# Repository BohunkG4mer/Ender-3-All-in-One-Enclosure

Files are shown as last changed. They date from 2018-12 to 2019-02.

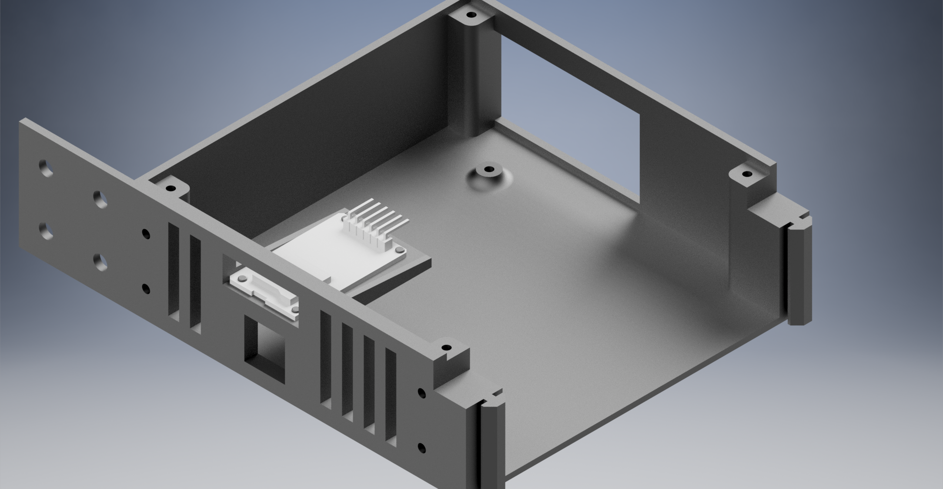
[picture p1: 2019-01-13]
Photos/card reader 2.png

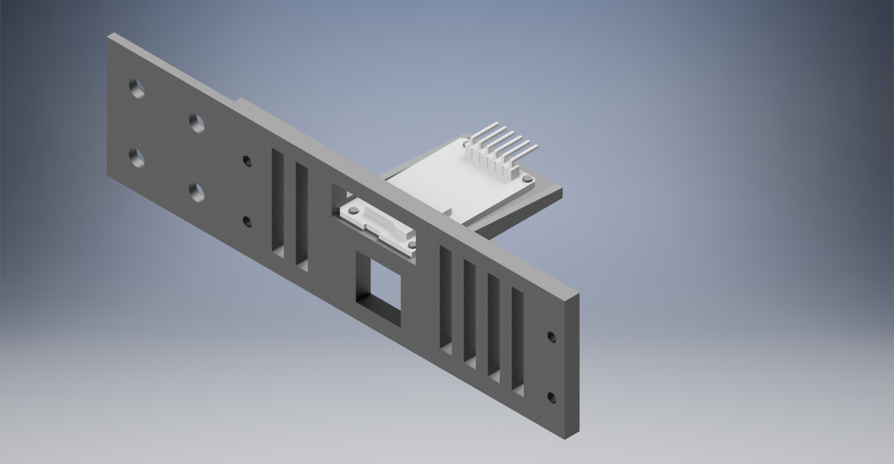
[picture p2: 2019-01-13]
Photos/card reader.png

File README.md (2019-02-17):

# Ender 3 All in One Modular Electronics Enclosure

This project is about making an all-in-one solution for upgrading your Ender 3 electronics. I started with the good old Ender 3, but quickly realized I wanted to expand the Ender 3's capabilities, and upgrade the original mainboard. I looked on Thingiverse, but couldn't really find a solution I liked. Thus began the journey of creating my own, all in one solution. I'm not new to CAD, but this is my first major project and my first Github thing, so bear with me and I'm totally open to suggestions and improvements.

Initially I started with these goals in mind:

- Be able to fit many types of mainboards, including the MKS Gen 1.4 and MKS Gen L.
- Be able to fit a Raspberry Pi internally for permanent installment, for use with Klipper firmware.
- Have a modular design to allow customization for the user's desires.
- Of course, have it all printable on a stock Ender 3.
- Be open source, and allow users to not only download and print as is, but create their own versions using my source files.
- Minimize material usage and print time when possible

Many improvements have been made and will continue to be made since the original upload on Thingiverse.  Because the Github was created later than the original project, V1.0 on Github is the newest version of the files uploaded to Thingiverse, and the next version on Github will likely be V2.0.

This Github project will let you follow the progress of my design journey, submit issues and design improvement suggestions, request additional modules and/or versions of parts, request added component compatibility, among other things. It is also the place to download all STLs and Source files, as I don't want to have to manage two separate pages and websites with the same files.

https://imgur.com/a/7V5CoWO

If you'd like to contribute to the development, feel free to donate.  It's very much appreciated!

http://paypal.me/BladeScraper

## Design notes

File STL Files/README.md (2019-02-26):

These are the STL files.

Parts and their discription:

## Base Left No Front Panel:
This is the left half of the main base. It doesn't have a front panel which makes printing much faster than previous versions of the enclosure.  The front panel is a separate part.

## Base Right No Front Panel:
This is the right half of the main base. It doesn't have a front panel which makes printing much faster than previous versions of the enclosure.  The front panel is a separate part.

## Base Left Front Panel:
This screws onto the base left part using M3x8 screws.  

## Base Right Front Panel:
This screws onto the base right part using M3x8 screws.  

## Base Cover Left:
This screws into the top of the base to cover it using M3x8 screws.

## Base Cover Right:
This screws into the top of the base to cover it using M3x8 screws.

## RPi3 Mount:
This is the Raspberry Pi3 mount module.  Screws onto the right base with M3x6 screws.  The Pi screws to it using M2.5x6 screws.

## Regulator Mount: 
This is for mounting LM2596 regulators and the MOSFET modules from Amazon.  Screws to the base using M3x6 screws.

## Base Left Front Panel Card Reader
For use with an Arduino SD Card reader.  Untested.
https://smile.amazon.com/WINGONEER-reader-module-interface-conversion/dp/B06XHJJWNC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

## Base Cover Left 80mm Fan
For use with a 80x10 or 80x25 fan.  Fan will mount on top of the cover as there's probably not sufficient room under it.  A 80x10 fan might work under the cover, but a 80x25 will definitely not.

## Base Cover Left 60mm Fan
This screws into the top of the base to cover it using M3x8 screws.

## Base Cover Right 80mm Fan
Added 80mm Fan Version of Base Cover Right.

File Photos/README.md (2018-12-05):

This folder contains photos of my personal Ender 3 with the electronics enclosure installed.  Mainly to be used as an example to look at when upgrading your own Ender 3.

The photos may not contain the latest designes immediately after release, but they should still give you a good reference to look at.

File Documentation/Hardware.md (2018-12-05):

This is a list of required hardware for assembly.

For Attaching the Front Panels to the Base parts:
- 8 x M3x8 Screws

For attaching RPi3 to RPi3 Mount: 
- 4 x M2.5x6 screws

For attaching RPi3 Mount to Base:
- 4 x M3x6 screws

For attaching MKS mainboard to Base:
- 4 x M3x6 screws

For attaching Base Cover left and Base Cover right:
- 4 x M3x8 per side

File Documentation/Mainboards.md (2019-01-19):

This is a list of current compatible mainboards for the enclosure.  

1. MKS Gen 1.4
2. MKS Gen L
3. MKS Rumba V1.0 (untested)

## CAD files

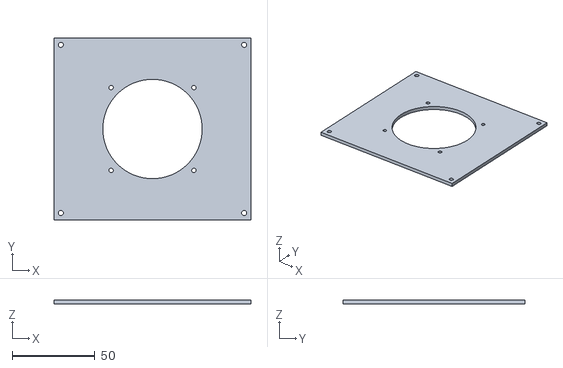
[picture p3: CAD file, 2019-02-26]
STL Files/Base Cover Left 60mm Fan.stl
119.0 x 110.2 x 2.50

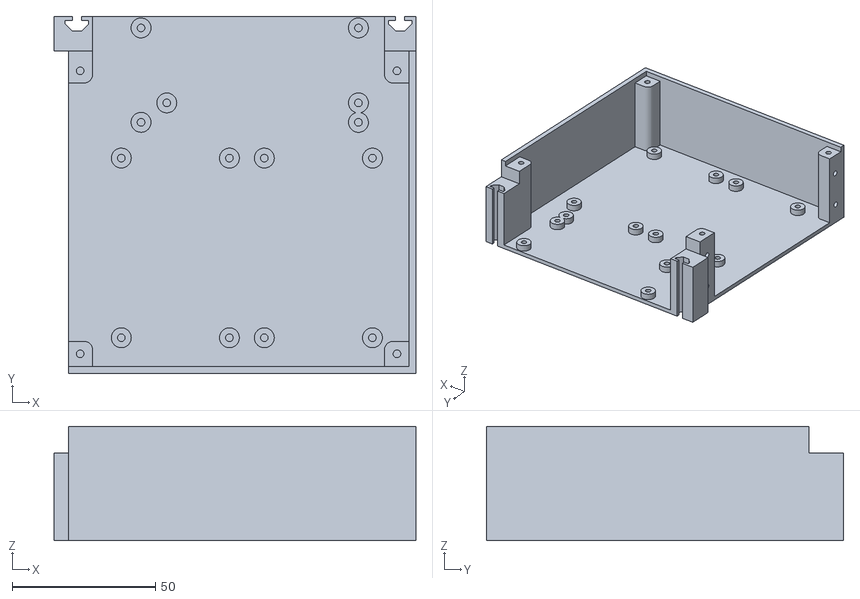
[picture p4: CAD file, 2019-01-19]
STL Files/Base Right No Front Panel.stl
126.5 x 124.8 x 40.0

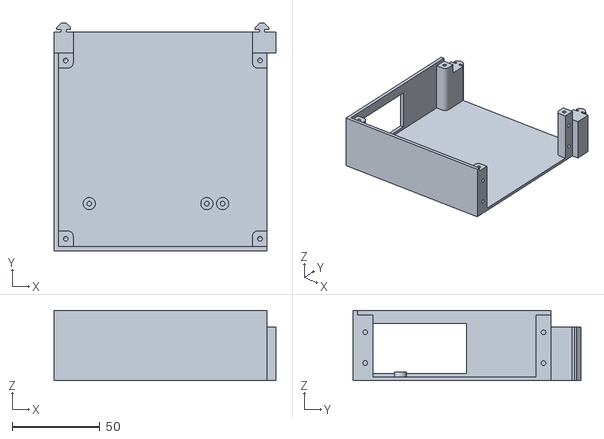
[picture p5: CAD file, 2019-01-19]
STL Files/Base Left No Front Panel.stl
126.5 x 129.7 x 40.0

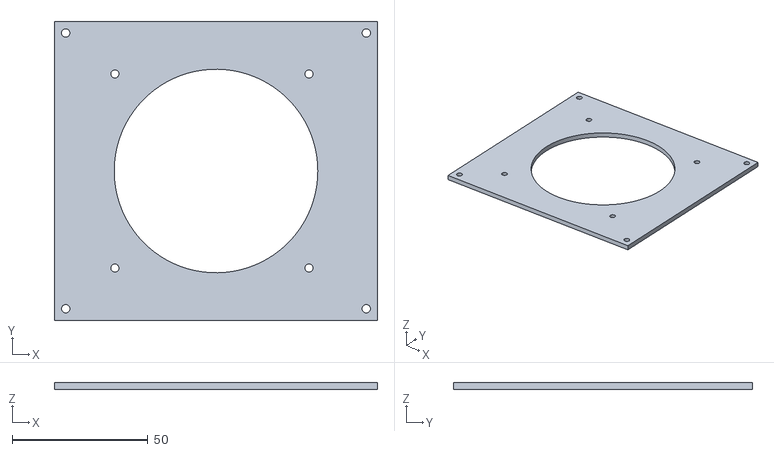
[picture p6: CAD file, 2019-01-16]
STL Files/Base Cover Left 80mm fan.stl
119.0 x 110.2 x 2.50

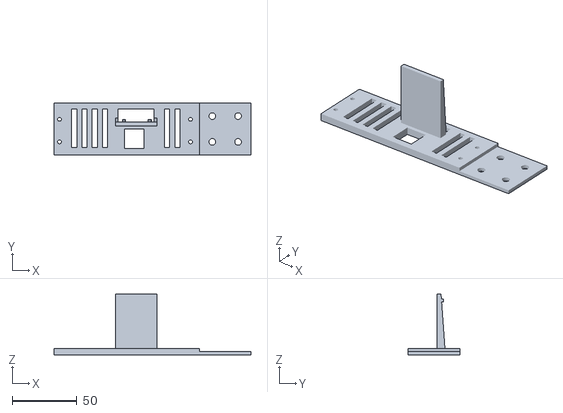
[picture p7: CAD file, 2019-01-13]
STL Files/Base Left Front Panel SD Reader.stl
152.7 x 40.0 x 47.0

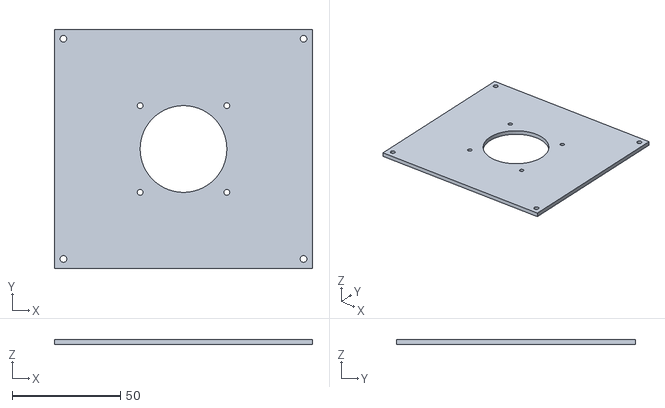
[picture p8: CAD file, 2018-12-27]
STL Files/Base Cover Left.stl
119.0 x 110.2 x 2.50

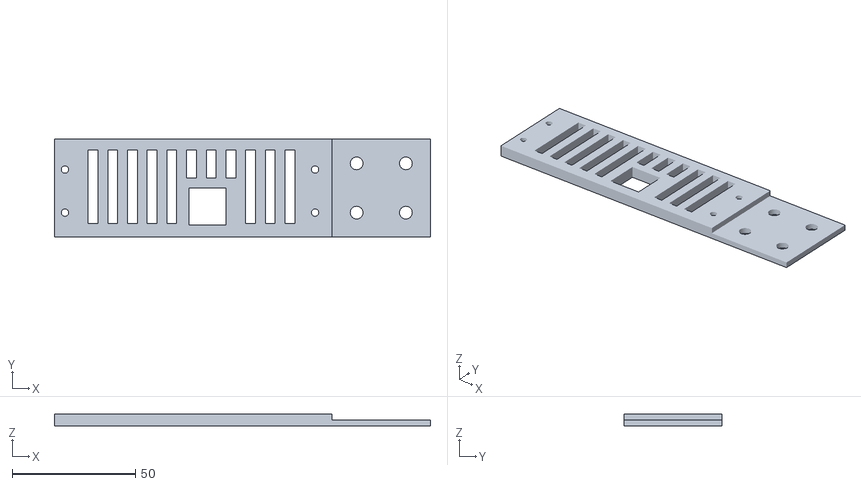
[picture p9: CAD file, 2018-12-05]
STL Files/Base Left Front Panel.stl
152.7 x 40.0 x 5.00

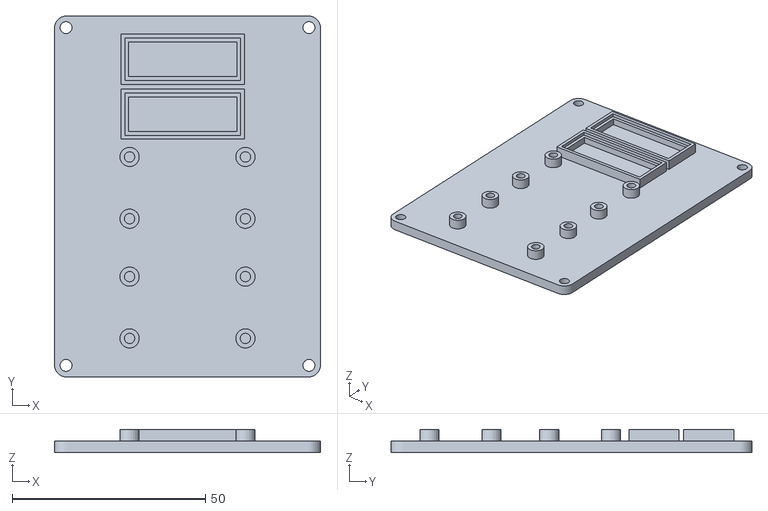
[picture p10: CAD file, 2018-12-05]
STL Files/Regulator_Mount.stl
68.9 x 93.5 x 6.00

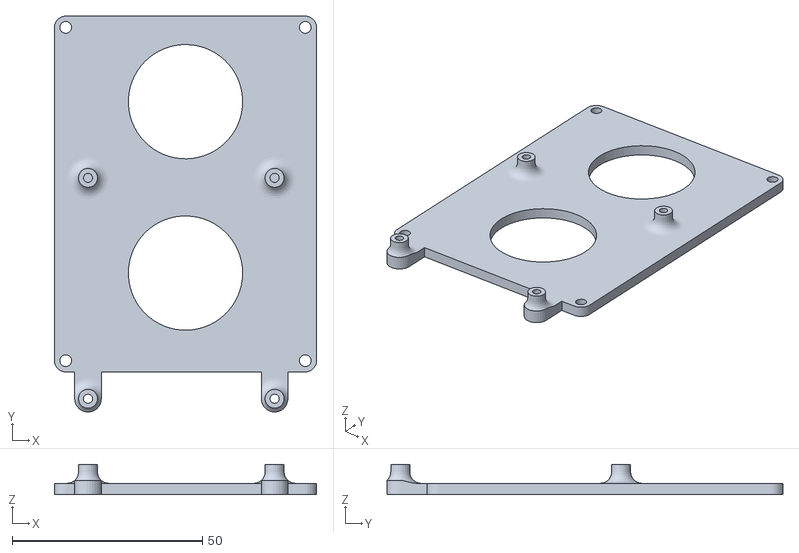
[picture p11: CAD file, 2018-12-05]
STL Files/RPi_3_Mount_V1.1.stl
68.9 x 104.0 x 8.00

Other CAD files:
STL Files/Base Right Front Panel.stl
STL Files/Base Cover Right 80mm Fan.stl
Source Files/Base Cover Left 60mm Fan.ipt
Source Files/Base Cover Left 80mm fan.ipt
Source Files/Base Cover Left.ipt
Source Files/Base Cover Right 80mm Fan.ipt
Source Files/Base Cover Right.ipt
Source Files/Base Left Front Panel SD Reader.ipt
Source Files/Base Left Front Panel.ipt
Source Files/Base Left No Front Panel.ipt
Source Files/Base Right Front Panel.ipt
Source Files/Base Right No Front Panel.ipt
Source Files/RPi 3 Mount.ipt
Source Files/Regulator Mount.ipt

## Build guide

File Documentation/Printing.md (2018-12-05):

Printing the parts is pretty straightforward.  STL orientation is pre-determined.  None of the parts should require supports.

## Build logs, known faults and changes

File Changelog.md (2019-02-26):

# Changelog
All notable changes to this project will be documented in this file.

## [1.0.0] - 2018-12-04
### Initial Release on Github
- Initial Release on Github

## [1.0.1] - 2018-12-05
### Small Change to Board Mounting Holes
- Increased outer diameter of the mounting holes in the Base Left and Base right as I was still experiencing some breaking off when tightening the screws.  Updated both the source files and STL files accordingly.  New outer diameter is 7mm, increased from 5mm in previous versions.

## [2.0.0] - 2018-12-05
### Major revision to the enclosure.  
- Removed front panel and made it a separate part for each half of the base.  This greatly reduces printing time compared to the old version.  The front panels screw onto the front of the base using M3 screws.
-Removed vertical grills from the back part of the base pieces.  Not only did they serve no purpose because they were against the 4040 extrusion in the back anyway, they increased printing time by a lot due to the printer having to print lots of individual towers instead of just one big wall.

## [2.0.1] - 2018-1-13
### Added Base Left Front Panel SD Reader.  
- This allows you to use a Arduino SD Card reader with your MKS mainboard.  Untested.
https://smile.amazon.com/WINGONEER-reader-module-interface-conversion/dp/B06XHJJWNC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

## [2.0.2] - 2018-1-16
### Added Base Cover Left 80mm Fan.
- This allows the use of a 80mm fan for mainboard cooling.  A 80x10 fan would be ideal, but a 80x25 fan should fit on top of the cover without colliding with the bed.

## [2.0.3] - 2018-1-18
### Add support for MKS Rumba V1.0
- Add mounting points for MKS Rumba.  User requested.  Untested.

## [2.0.4] - 2018-2-26
### Add Base Cover Left with 60mm Fan Holes

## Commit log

2018-12-05 Create Printing
2019-01-16 Add files via upload
    Added 80mm fan version of Base Cover Left
    [Base Cover Left 80mm fan.ipt]
2019-01-19 Add files via upload
    Add mounts for MKS Rumba V1.0
    [Base Left No Front Panel.ipt, Base Right No Front Panel.ipt]
2019-02-26 Add Base Cover Left 60mm Fan
    [Base Cover Left 60mm Fan.ipt]
2019-02-26 Add Base Cover Right 80mm Fan
    [Base Cover Right 80mm Fan.stl]
